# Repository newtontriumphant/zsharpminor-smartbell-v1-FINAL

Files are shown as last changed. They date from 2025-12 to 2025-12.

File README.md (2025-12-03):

# zsharpminor's SmartBell, v1!

Hi, thanks for reviewing my project! ;w; This is an ESP32-powered smart doorbell with smart AI-powered detection, that automatically captures a picture that is sent to a Discord webhook via WiFi when the doorbell is rung, which triggers an integration that can set off a custom ringtone on a mobile app. Features near-waterproof PETG/TPU case and a temperature sensor that automatically reports Temperature and Humidity to said webhook as well. Additionally, an ultrasonic sensor detects movement and wakes up the camera to take a picture and identify it through a simple ML algorithm. NOTE: This is a software-heavy project, I am aiming for this to be a Tier 4 project, and Tanook agreed that it qualifies as Tier 4 (under the condition that a CAD case exists, which it does!).

I built this project for a few reasons: firstly, the doorbell I have is non-functional, and I can't be asked to give Amazon 100 dollars of my hard-earned money to sell my data through a Ring doorbell. Secondly, I wanted some more experience in building a near-100% waterproof case design with PETG and TPU gaskets. The goal of this project was to keep the total cost under half that of a commercially available substitute - and still get the thrill of designing it myself; I think that I did a good job. Screenshots of the CAD design (both assembled and unassembled) are at the bottom of the README.

BOM CSV FILE: https://docs.google.com/spreadsheets/d/1LvQgwua6umSP1ob7BG9KYe2bF_PC_YEmnamfS4FcfZg/

(BOM and placement CSV files also placed inside the PCB folder for easy access).

# BOM:

**GRANT REQUIRED: $30.00**

Screenshots of Carts:

1x SEEED Studios

Screenshot 2025-12-02 at 7 53 21 PM

1x JLCPCB

Screenshot 2025-12-02 at 7 56 57 PM

Grant:

* 1x SEEED Studios XIAO ESP32-S3 SENSE (**requires Grant**).
* 1x 2-Layer JLCPCB (**requires Grant**).

Self-Provided:

* 1x Standard Active Buzzer (Self-Provided)
* 1x 5mm Diameter Green Standard LED (Self-Provided)
* 1x 330 Ohm Resistor for LED (Self-Provided)
* 1x 12mm Tactswitch and Cover (Self-Provided)
* 4x Female Header, Right Angle (Self-Provided)
* 1x Adafruit STEMMA QT to 4-pin Male Cable (Self-Provided)
* 1x Adafruit AHT20 STEMMA I2C Temp/Humi Sensor (Self-Provided)
* 1x HC-SR04 45 x 70 mm Ultrasonic Sensor (Self-Provided)
* 1x 1500mah JST LiPo Battery (Self-Provided)

* 1x Case to be entirely 3d-printed in near-waterproof PETG with TPU seals (self-provided), iterations may occur.

(NOTE: the case intentionally has an empty space to the right; this is for the AHT20 temp/humi sensor as well as a LiPo battery (I'm experimenting with a few battery sizes!)

PCB will be glued to the back of the case, and the top will be water sealed with a TPU gasket and water-resistant sealant.

# Empty CAD case:

Screenshot 2025-12-02 at 7 40 02 PM

Screenshot 2025-12-02 at 7 40 08 PM

# Final CAD model with case, showcasing how the components fit together:

## No. 1: PCB in case without top:

Screenshot 2025-12-02 at 7 38 25 PM

## No. 2: PCB in case with top:

Screenshot 2025-12-02 at 7 38 45 PM

## No. 3: Side-View of USB-C port and tapered edges

Screenshot 2025-12-02 at 7 39 04 PM

# Schematic:

Screenshot 2025-12-02 at 7 36 44 PM

# PCB:

Screenshot 2025-12-02 at 7 36 56 PM

# PCB 3d Render:

Screenshot 2025-12-02 at 7 37 14 PM

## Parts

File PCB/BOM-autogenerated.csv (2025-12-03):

Id | Designator | Footprint | Quantity | Designation | Supplier and ref
1 | BZ1 | Buzzer_12x9.5RM7.6 | 1 | Buzzer
2 | SW1 | SW_PUSH-12mm | 1 | SW_Push
3 | R1 | R_Axial_DIN0207_L6.3mm_D2.5mm_P10.16mm_Horizontal | 1 | R
4 | U1 | XIAO-ESP32S3-DIP | 1 | XIAO-ESP32-S3-DIP
5 | J2 | PinHeader_1x04_P2.54mm_Horizontal | 1 | stemma
6 | D1 | LED_D5.0mm | 1 | LED
7 | J1 | PinHeader_1x04_P2.54mm_Horizontal | 1 | Conn_01x04

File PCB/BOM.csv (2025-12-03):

GRANT Items | Description | Quantity | Unit Price ($) | Total Price ($) | URL | NET PRICE | Running Total
SEEED Studios XIAO ESP32-S3-SENSE DIP | Micro | 1 | 12.59 | 12.59 | https://www.seeedstudio.com/XIAO-ESP32S3-Sense-p-5639.html | 19.01 | 19.01
JLCPCB | PCB | 1 | 0.8 | 4 (MOQ 5) | https://cart.jlcpcb.com/quote?stencilLayer=2&stencilWidth=100&stencilLength=100&stencilCounts=5 | 4.29 | 23.3
JLCPCB Shipping | PCB | 1 | 4 | 4 | N/A - Global Standard Direct Line, Cheapest Option. | 4.29 | 27.59
FINAL PRICE FOR GRANT ITEMS: | $30.00 | (rounded from $27.59 | due to tariffs)
SELF-PROVIDED Items | Description | Quantity | Unit Price ($)
3D-printed case (SELF-PROVIDED) | Approx. 156g of PETG/TPU | 1 | 0
Standard Active Buzzer (SELF-PROVIDED) | Doorbell Sound | 1 | 0
Standard 5mm Green LED (SELF-PROVIDED) | Doorbell LED | 1 | 0
330 Ohm Resistor (SELF-PROVIDED) | LED Resistor | 1 | 0
12mm Tactswitch And Cover (SELF-PROVIDED) | Switch for Bell | 1 | 0
RA Female Header (SELF-PROVIDED) | Header for STEMMA | 4 | 0
STEMMA to Male Cable (SELF-PROVIDED) | Cable to connect AHT20 | 1 | 0
AHT20 STEMMA Sensor (SELF-PROVIDED) | Temp / Humi Sensor | 1 | 0
HC-SR04 Sensor (SELF-PROVIDED) | Ultrasonic Sensor | 1 | 0
1500mah JST battery (SELF-PROVIDED) | Power for Doorbell | 1 | 0
NOTE: I DO **NOT** NEED A GRANT
FOR ANY OF THE SELF PROVIDED ITEMS.

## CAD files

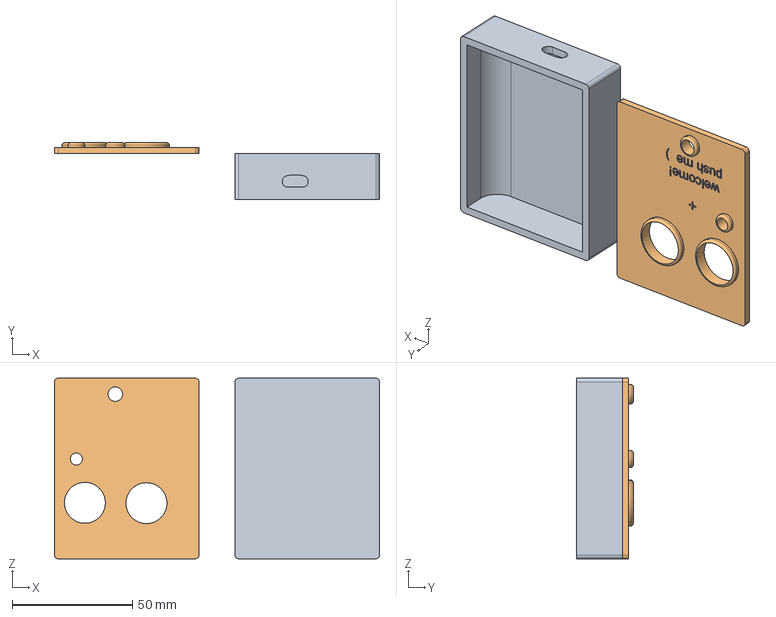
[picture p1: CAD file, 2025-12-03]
CAD/zsharpminor-SmartBell-Case-FINAL.step
135.0 x 23.5 x 75.0 mm

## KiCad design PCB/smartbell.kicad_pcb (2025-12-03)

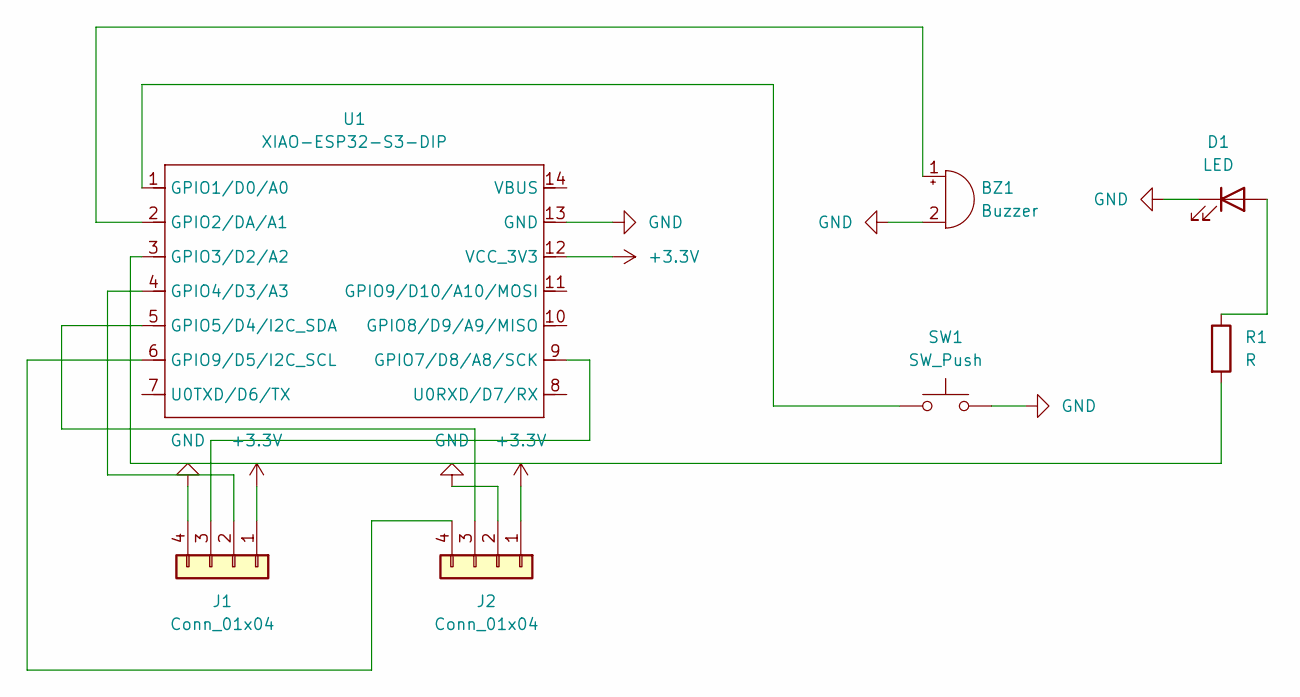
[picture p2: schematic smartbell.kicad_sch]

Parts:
BZ1: Buzzer; Buzzer_12x9.5RM7.6
D1: LED; LED_D5.0mm
J1, J2: Conn_01x04; PinHeader_1x04_P2.54mm_Horizontal
R1: R; R_Axial_DIN0207_L6.3mm_D2.5mm_P10.16mm_Horizontal
SW1: SW_Push; SW_PUSH-12mm
U1: XIAO-ESP32-S3-DIP; XIAO-ESP32S3-DIP

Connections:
+3.3V: J1.1, J2.1, U1.12 (VCC_3V3)
GND: BZ1.2 (-), D1.1 (K), J1.4, J2.2, SW1.2, U1.13 (GND)
unnamed: BZ1.1 (+), U1.2 (GPIO2/DA/A1)
unnamed: D1.2 (A), R1.1
unnamed: J1.2, U1.4 (GPIO4/D3/A3)
unnamed: J1.3, U1.9 (GPIO7/D8/A8/SCK)
unnamed: J2.3, U1.5 (GPIO5/D4/I2C_SDA)
unnamed: J2.4, U1.6 (GPIO9/D5/I2C_SCL)
unnamed: SW1.1, U1.1 (GPIO1/D0/A0)
unnamed: R1.2, U1.3 (GPIO3/D2/A2)

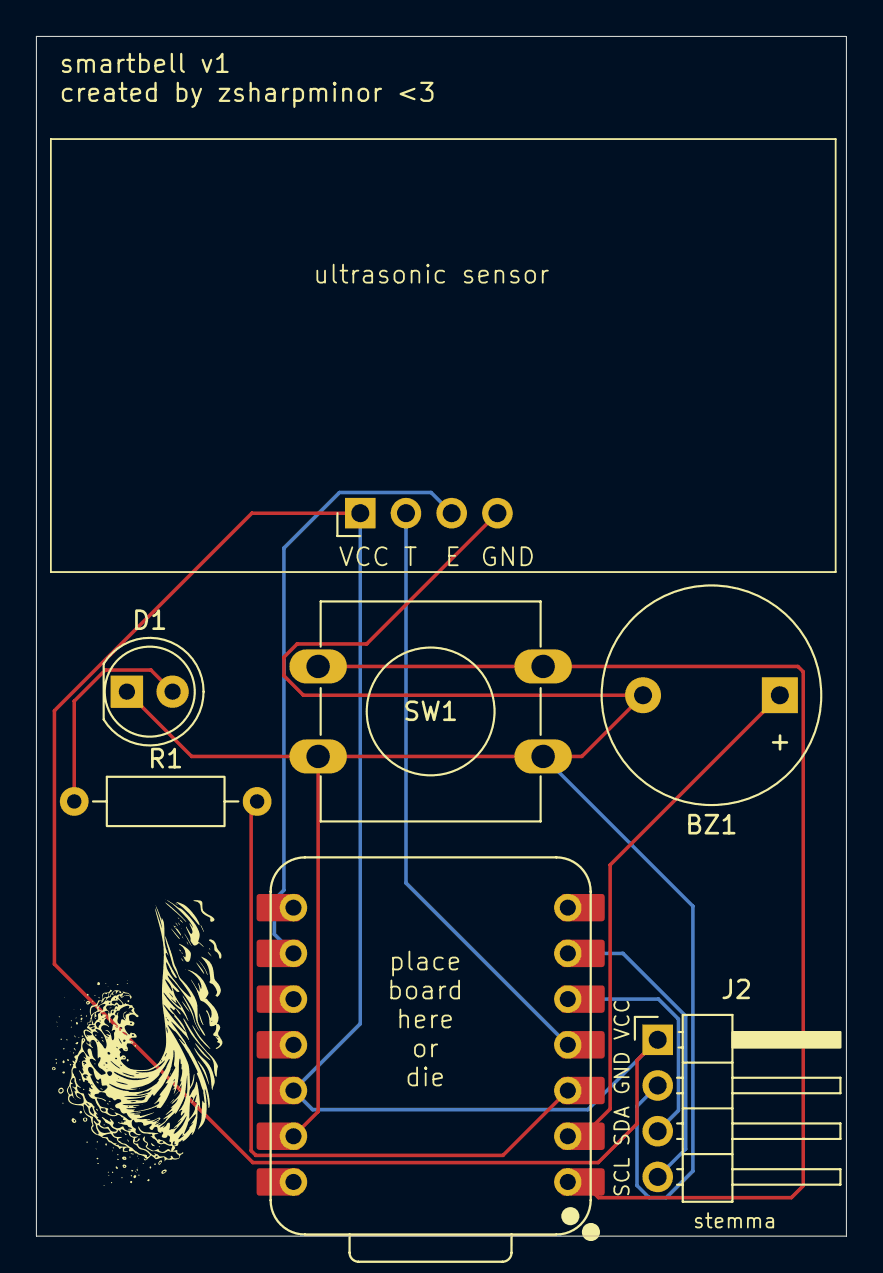
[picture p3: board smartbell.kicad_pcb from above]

Board: 2 copper layers, 45.0 x 66.7 mm, 7 parts (0 on the bottom side), 10 nets.

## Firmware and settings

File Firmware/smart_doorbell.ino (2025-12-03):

#include <WiFi.h>
#include <WiFiClientSecure.h>
#include "esp_camera.h"
#include <Wire.h>
#include <Adafruit_AHTX0.h>

const char *WIFI_SSID     = "BLANK_FOR_SECURITY_REASONS";
const char *WIFI_PASSWORD = "BLANK_DITTO";

const char *DISCORD_HOST = "discord.com";
const char *DISCORD_PATH =
  "/api/webhooks/1428854392655708231/"
  "ndoVAxldr4pqDMZOqxiD_aN-xoe7i-uEq-vfJGrtfNGJsD6mkCE5v6PfY2Ki7gLd4CIq";

const float MOTION_DISTANCE_CM = 200.0;
const unsigned long ULTRASONIC_INTERVAL_MS = 5000;
const unsigned long AHT20_REPORT_INTERVAL_MS = 3600000UL;

#define PIN_BUTTON   D0
#define PIN_BUZZER   D1
#define PIN_LED      D2
#define PIN_US_TRIG  D3
#define PIN_US_ECHO  D8
#define PIN_I2C_SDA  D4
#define PIN_I2C_SCL  D5

#define PWDN_GPIO_NUM     -1
#define RESET_GPIO_NUM    -1
#define XCLK_GPIO_NUM     10
#define SIOD_GPIO_NUM     40
#define SIOC_GPIO_NUM     39
#define Y9_GPIO_NUM       48
#define Y8_GPIO_NUM       11
#define Y7_GPIO_NUM       12
#define Y6_GPIO_NUM       14
#define Y5_GPIO_NUM       16
#define Y4_GPIO_NUM       18
#define Y3_GPIO_NUM       17
#define Y2_GPIO_NUM       15
#define VSYNC_GPIO_NUM    38
#define HREF_GPIO_NUM     47
#define PCLK_GPIO_NUM     13

Adafruit_AHTX0 aht20;

unsigned long lastUltrasonicCheck = 0;
unsigned long lastAHTReport = 0;
int lastButtonState = HIGH;

void connectWiFi() {
  WiFi.mode(WIFI_STA);
  WiFi.begin(WIFI_SSID, WIFI_PASSWORD);
  Serial.print("Connecting to WiFi");
  while (WiFi.status() != WL_CONNECTED) {
    delay(500);
    Serial.print(".");
  }
  Serial.println("\nWiFi connected. IP: " + WiFi.localIP().toString());
}

bool initCamera() {
  camera_config_t config;
  config.ledc_channel = LEDC_CHANNEL_0;
  config.ledc_timer   = LEDC_TIMER_0;
  config.pin_d0       = Y2_GPIO_NUM;
  config.pin_d1       = Y3_GPIO_NUM;
  config.pin_d2       = Y4_GPIO_NUM;
  config.pin_d3       = Y5_GPIO_NUM;
  config.pin_d4       = Y6_GPIO_NUM;
  config.pin_d5       = Y7_GPIO_NUM;
  config.pin_d6       = Y8_GPIO_NUM;
  config.pin_d7       = Y9_GPIO_NUM;
  config.pin_xclk     = XCLK_GPIO_NUM;
  config.pin_pclk     = PCLK_GPIO_NUM;
  config.pin_vsync    = VSYNC_GPIO_NUM;
  config.pin_href     = HREF_GPIO_NUM;
  config.pin_sscb_sda = SIOD_GPIO_NUM;
  config.pin_sscb_scl = SIOC_GPIO_NUM;
  config.pin_pwdn     = PWDN_GPIO_NUM;
  config.pin_reset    = RESET_GPIO_NUM;
  config.xclk_freq_hz = 20000000;
  config.pixel_format = PIXFORMAT_JPEG;

  if (psramFound()) {
    config.frame_size   = FRAMESIZE_VGA;
    config.jpeg_quality = 10;
    config.fb_count     = 2;
  } else {
    config.frame_size   = FRAMESIZE_QVGA;
    config.jpeg_quality = 12;
    config.fb_count     = 1;
  }

  esp_err_t err = esp_camera_init(&config);
  if (err != ESP_OK) {
    Serial.printf("Camera init failed with error 0x%x\n", err);
    return false;
  }
  Serial.println("Camera initialized.");
  return true;
}

bool captureAndSendImage(const char *caption) {
  camera_fb_t *fb = esp_camera_fb_get();
  if (!fb) {
    Serial.println("Camera capture failed");
    return false;
  }

  bool ok = false;
  WiFiClientSecure client;
  client.setInsecure();

  if (!client.connect(DISCORD_HOST, 443)) {
    Serial.println("Connection to Discord failed");
  } else {
    String boundary = "------------------------XIAODOORBELL12345";
    String bodyStart = "--" + boundary + "\r\n";
    bodyStart += "Content-Disposition: form-data; name=\"content\"\r\n\r\n";
    bodyStart += caption;
    bodyStart += "\r\n--" + boundary + "\r\n";
    bodyStart += "Content-Disposition: form-data; name=\"file\"; filename=\"doorbell.jpg\"\r\n";
    bodyStart += "Content-Type: image/jpeg\r\n\r\n";

    String bodyEnd = "\r\n--" + boundary + "--\r\n";
    size_t totalLen = bodyStart.length() + fb->len + bodyEnd.length();

    client.print(String("POST ") + DISCORD_PATH + " HTTP/1.1\r\n");
    client.print(String("Host: ") + DISCORD_HOST + "\r\n");
    client.print("User-Agent: XIAO-ESP32S3-doorbell\r\n");
    client.print("Content-Type: multipart/form-data; boundary=" + boundary + "\r\n");
    client.print("Content-Length: ");
    client.print(totalLen);
    client.print("\r\nConnection: close\r\n\r\n");

    client.print(bodyStart);
    client.write(fb->buf, fb->len);
    client.print(bodyEnd);

    unsigned long timeout = millis() + 10000;
    while (client.connected() && millis() < timeout) {
      while (client.available()) {
        String line = client.readStringUntil('\n');
        Serial.println(line);
      }
    }
    ok = true;
  }

  esp_camera_fb_return(fb);
  client.stop();
  return ok;
}

bool sendDiscordText(const String &content) {
  WiFiClientSecure client;
  client.setInsecure();

  if (!client.connect(DISCORD_HOST, 443)) {
    Serial.println("Connection to Discord failed (text)");
    return false;
  }

  String payload = String("{\"content\":\"") + content + "\"}";

  String request =
      String("POST ") + DISCORD_PATH + " HTTP/1.1\r\n" +
      "Host: " + DISCORD_HOST + "\r\n" +
      "User-Agent: XIAO-ESP32S3-doorbell\r\n" +
      "Content-Type: application/json\r\n" +
      "Content-Length: " + String(payload.length()) + "\r\n" +
      "Connection: close\r\n\r\n" +
      payload;

  client.print(request);

  unsigned long timeout = millis() + 10000;
  while (client.connected() && millis() < timeout) {
    while (client.available()) {
      String line = client.readStringUntil('\n');
      Serial.println(line);
    }
  }

  client.stop();
  return true;
}

float readUltrasonicDistanceCM() {
  digitalWrite(PIN_US_TRIG, LOW);
  delayMicroseconds(2);
  digitalWrite(PIN_US_TRIG, HIGH);
  delayMicroseconds(10);
  digitalWrite(PIN_US_TRIG, LOW);

  unsigned long duration = pulseIn(PIN_US_ECHO, HIGH, 30000UL);
  if (duration == 0) {
    return -1.0;
  }

  float distance = (duration * 0.0343) / 2.0;
  return distance;
}

bool initAHT20() {
  if (!aht20.begin()) {
    Serial.println("Could not find AHT20 sensor, check wiring.");
    return false;
  }
  Serial.println("AHT20 initialized.");
  return true;
}

bool readAHT20(float &tempC, float &humidity) {
  sensors_event_t humidity_event, temp_event;
  if (!aht20.getEvent(&humidity_event, &temp_event)) {
    return false;
  }
  tempC = temp_event.temperature;
  humidity = humidity_event.relative_humidity;
  return true;
}

void doorbellBuzzSequence() {
  digitalWrite(PIN_LED, HIGH);
  digitalWrite(PIN_BUZZER, HIGH);
  delay(1000);

  captureAndSendImage("Doorbell pressed - snapshot");

  digitalWrite(PIN_LED, LOW);
  digitalWrite(PIN_BUZZER, HIGH);
  delay(1000);

  digitalWrite(PIN_BUZZER, LOW);
}

void setup() {
  Serial.begin(115200);
  delay(1000);

  pinMode(PIN_BUZZER, OUTPUT);
  pinMode(PIN_LED, OUTPUT);
  pinMode(PIN_BUTTON, INPUT_PULLUP);
  pinMode(PIN_US_TRIG, OUTPUT);
  pinMode(PIN_US_ECHO, INPUT);

  digitalWrite(PIN_BUZZER, LOW);
  digitalWrite(PIN_LED, LOW);
  digitalWrite(PIN_US_TRIG, LOW);

  Wire.begin(PIN_I2C_SDA, PIN_I2C_SCL);

  connectWiFi();
  initCamera();
  initAHT20();

  lastUltrasonicCheck = millis();
  lastAHTReport = millis();
}

void loop() {
  unsigned long now = millis();

  int buttonState = digitalRead(PIN_BUTTON);
  if (lastButtonState == HIGH && buttonState == LOW) {
    Serial.println("Doorbell pressed!");
    doorbellBuzzSequence();
  }
  lastButtonState = buttonState;

  if (now - lastUltrasonicCheck >= ULTRASONIC_INTERVAL_MS) {
    lastUltrasonicCheck = now;
    float dist = readUltrasonicDistanceCM();
    Serial.print("Ultrasonic distance: ");
    Serial.println(dist);

    if (dist > 0 && dist < MOTION_DISTANCE_CM) {
      Serial.println("Motion detected by ultrasonic sensor!");
      captureAndSendImage("Motion detected at door");
    }
  }

  if (now - lastAHTReport >= AHT20_REPORT_INTERVAL_MS) {
    lastAHTReport = now;
    float t, h;
    if (readAHT20(t, h)) {
      String msg = "Hourly environment report: ";
      msg += String(t, 1) + " C, ";
      msg += String(h, 1) + " % RH";
      sendDiscordText(msg);
      Serial.println(msg);
    } else {
      Serial.println("Failed to read AHT20");
    }
  }

  delay(10);
}

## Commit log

2025-12-03 Updated README with BOM and extensive proof. Please approve ;w;
2025-12-03 added PCB directory
2025-12-03 Added ALL Final PCB files.
    [BOM-autogenerated.csv, BOM.csv, smartbell.kicad_pcb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]
2025-12-03 Added ALL Final PCB Files. <3
2025-12-03 Added Final Case CAD File
    [zsharpminor-SmartBell-Case-FINAL.step]
2025-12-03 Added Final CAD Files <3
2025-12-03 Added 3D Model of PCB Only <3
